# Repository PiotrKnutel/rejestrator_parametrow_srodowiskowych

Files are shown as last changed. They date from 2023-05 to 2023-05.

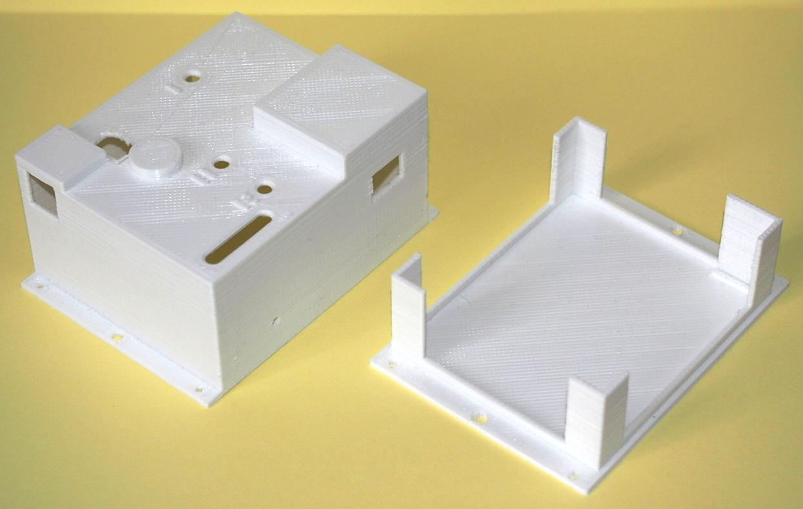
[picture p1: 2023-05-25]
zdjęcia/P2138913_v1.JPG

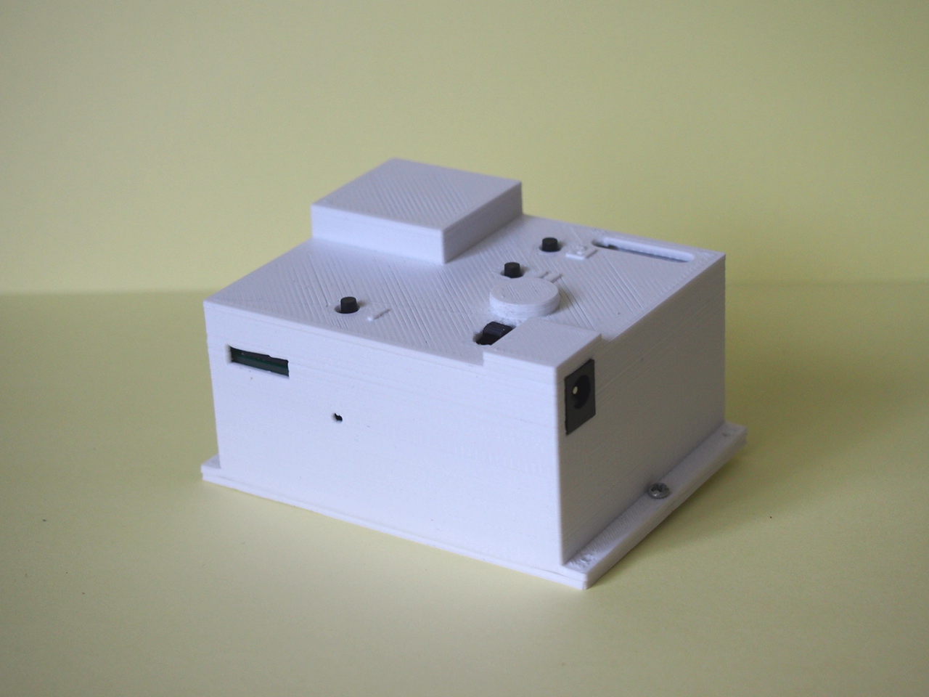
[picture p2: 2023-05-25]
zdjęcia/P2138927_v1.JPG

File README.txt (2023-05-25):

Projekt: Rejestaror Parametrów Środowiskowych
Project: The Recorder of Environmental Parameters
Autor/Author: Piotr Knutel (piknut@linux.pl), 2020-2021

Rejestrator dokonuje pomiarów: temperatury, ciśnienia
i wilgotności względnej powietrza atmosferycznego.

Projekt oparto o mikrokontroler z rodziny STM32
(STM32F103RC), cyfrowy czujnik BME280 i kartę micro-SD.

Pomiary wykonywane są cyklicznie (co ustalony czas,
np. 5, 10, 15, 30 min) lub na żądanie użytkownika
(przez naciśnięcie przycisku). Wyniki zapisywane są
w plikach CSV, na karcie SD. Ustawienia urządzenia
wprowadza się i odczytuje poprzez opracowaną aplikację
komputerową, która komunikuje się z rejestratorem,
przez wirtualny port szeregowy i przewód USB.  

Rejestrator może być stosowane do długookresowych
badań środowisk – takich jak miejsca funkcjonowania
ludzi i maszyn, magazyny oraz kontenery towarowe
– lub jako domowa stacja pogodowa. Urządzenie może
być zasilane przewodowo lub bateryjnie. 

Projekt obejmuje:
- schemat i projekt PCB (w programie KiCAD);
- program mikroprocesora STM32F103RC (w języku C,
  w oparciu o STMCube);
- terminalową aplikację komputerową do wprowadzania
  i odczytu ustawień poprzez port szeregowy (w języku
  C#, dla Windows i Linux);
– projekt obudowy (w programie FreeCAD).

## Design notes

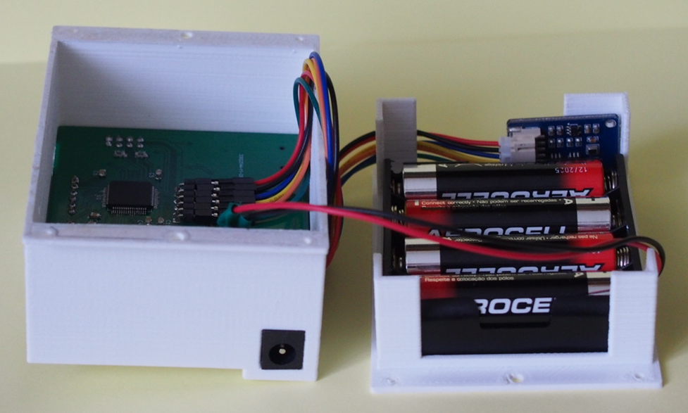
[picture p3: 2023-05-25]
zdjęcia/P2138917_v1.JPG

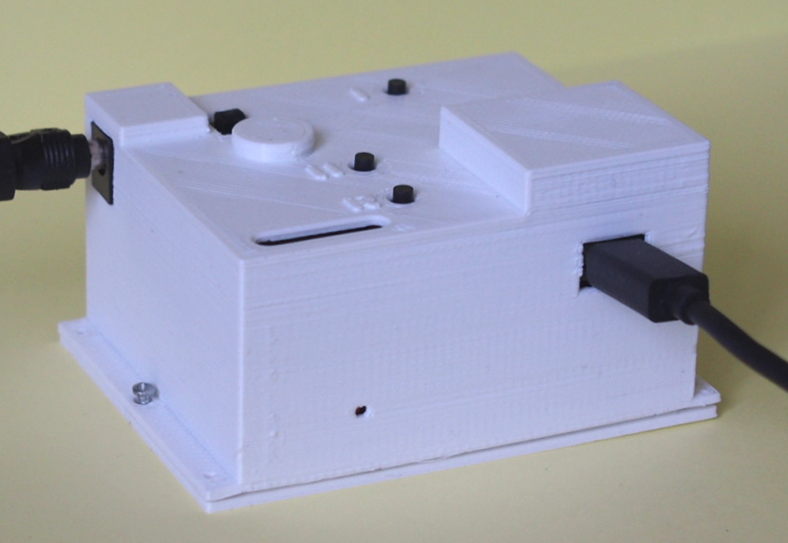
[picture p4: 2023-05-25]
zdjęcia/P2138921_v1.JPG

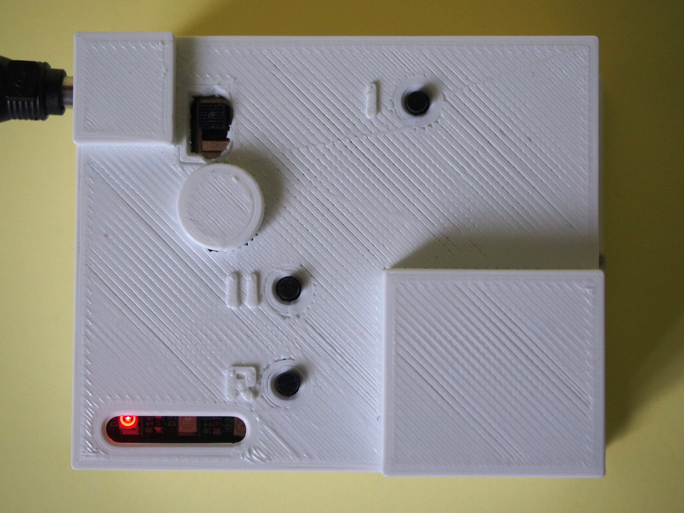
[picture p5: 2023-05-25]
zdjęcia/P2138924_v1.JPG

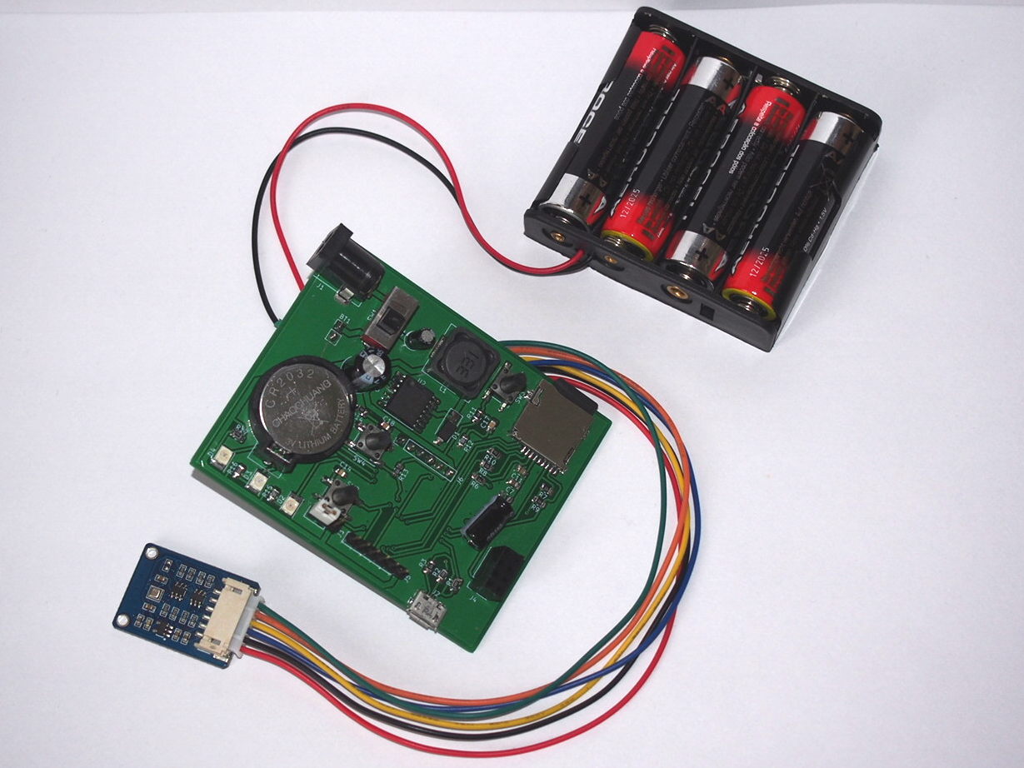
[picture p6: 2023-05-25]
zdjęcia/P2138910_v1.JPG

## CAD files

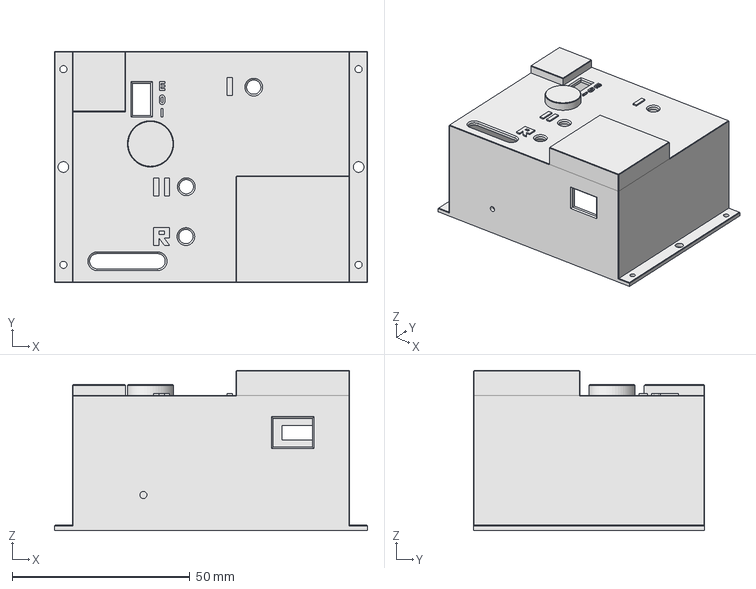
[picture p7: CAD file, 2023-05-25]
projekt_obudowy_FreeCAD/obudowa_rps.FCStd
88.0 x 65.0 x 45.0 mm

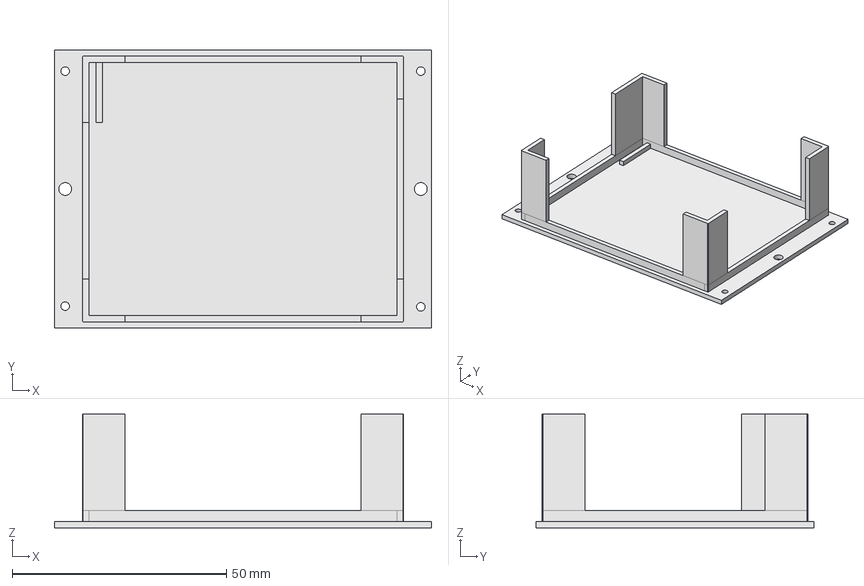
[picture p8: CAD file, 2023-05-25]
projekt_obudowy_FreeCAD/rps_obudowa_dol.FCStd
88.0 x 65.0 x 26.5 mm

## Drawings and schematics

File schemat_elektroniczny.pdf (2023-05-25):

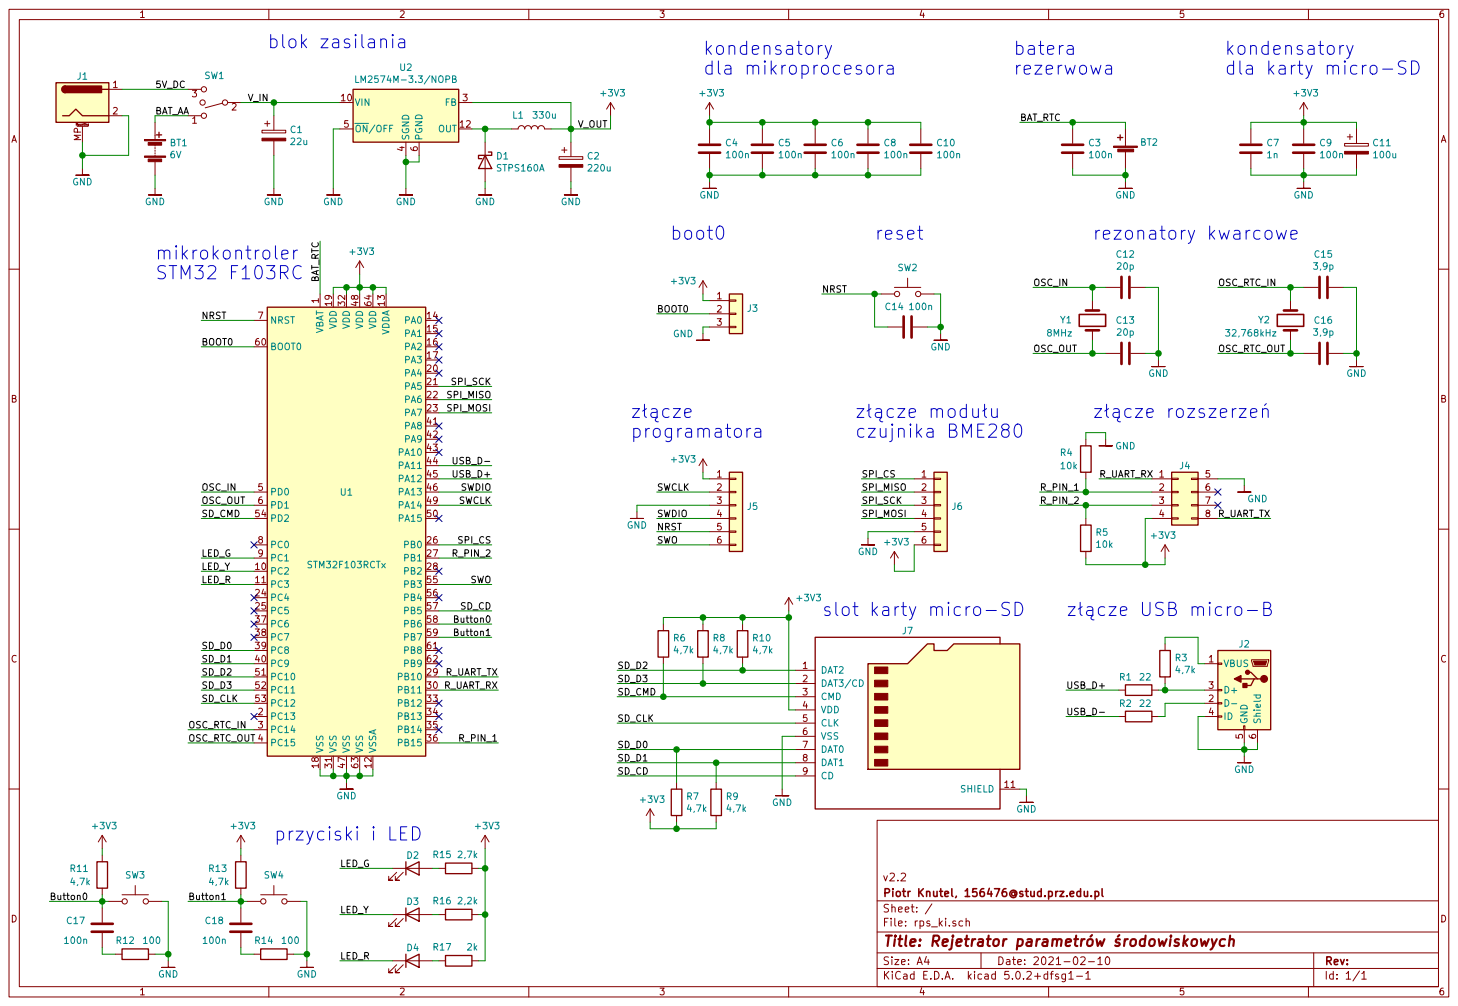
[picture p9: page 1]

kondensatory
dla karty micro-SD

1 PC2 10 PC3 11 VSSA 12 VDDA 13 PA0 14 PA1 15 PA2 16 PA3 17 VSS 18 VDD 19 PC13 2 PA4 20 PA5 21 PA6 22 PA7 23 PC4 24 PC5 25 PB0 26 PB1 27 PB2 28 PB10 29 PC14 3 PB11 30 VSS 31 VDD 32 PB12 33 PB13 34 PB14 35 PB15 36 PC6 37 PC7 38 PC8 39 PC15 4 PC9 40 PA8 41 PA9 42 PA10 43 PA11 44 PA12 45 PA13 46 VSS 47 VDD 48 PA14 49 PD0 5 PA15 50 PC10 51 PC11 52 PC12 53 PD2 54 PB3 55 PB4 56 PB5 57 PB6 58 PB7 59 PD1 6 BOOT0 60 PB8 61 PB9 62 VSS 63 VDD 64 NRST 7 PC0 8 PC1 9 U1 STM32F103RCTx BT2

File: rps_ki.sch Sheet: / Piotr Knutel, 156476@stud.prz.edu.pl v2.2 VBAT

slot karty micro-SD

Id: 1/1 Title: Rejetrator parametrów rodowiskowych

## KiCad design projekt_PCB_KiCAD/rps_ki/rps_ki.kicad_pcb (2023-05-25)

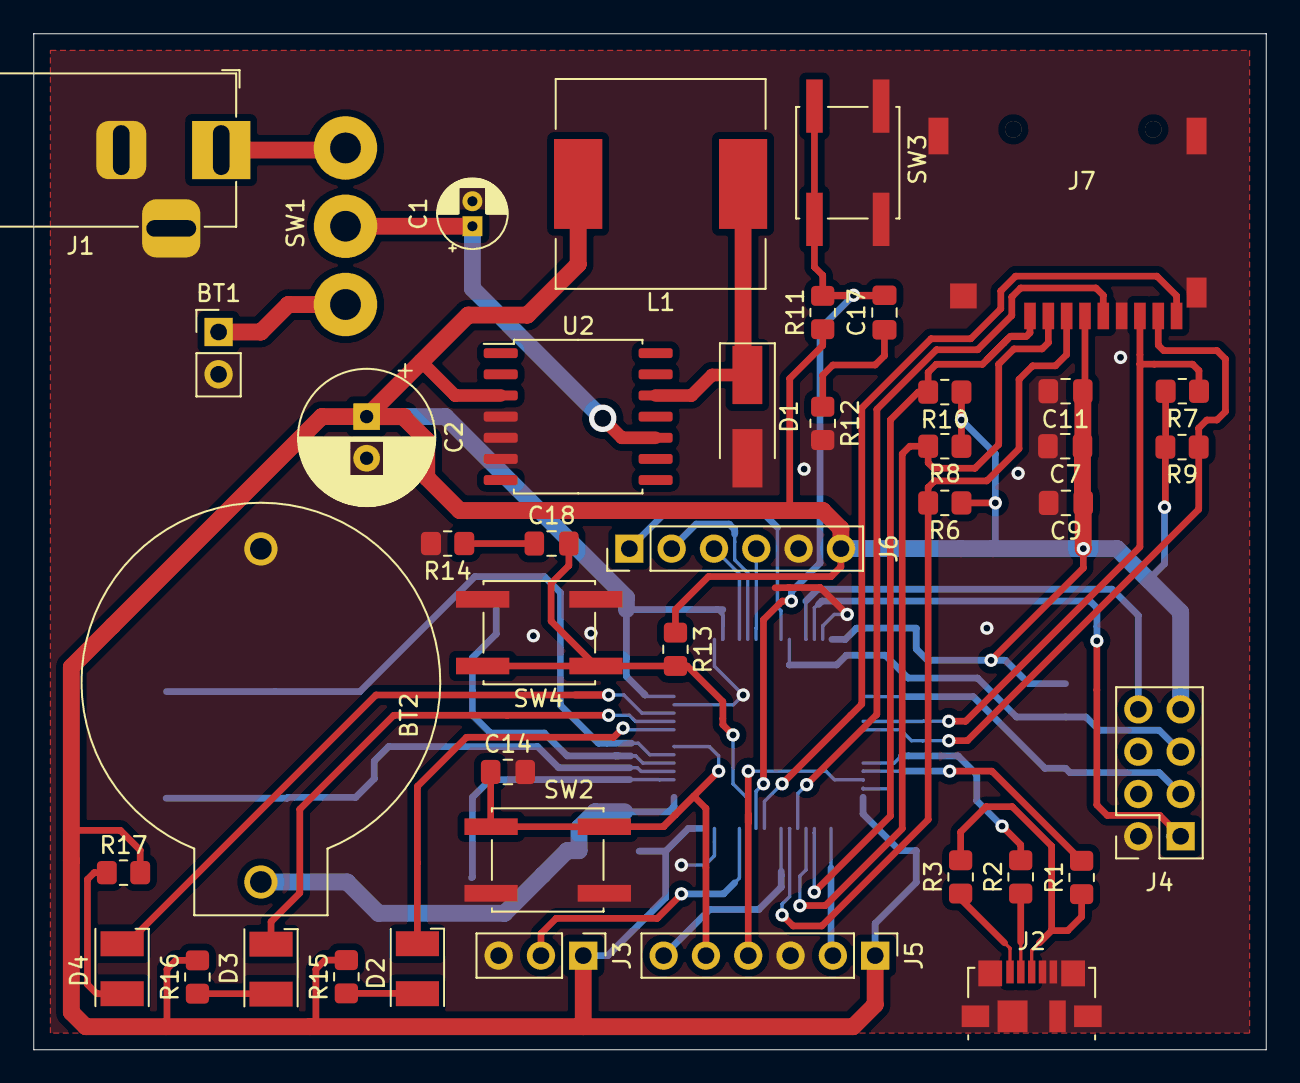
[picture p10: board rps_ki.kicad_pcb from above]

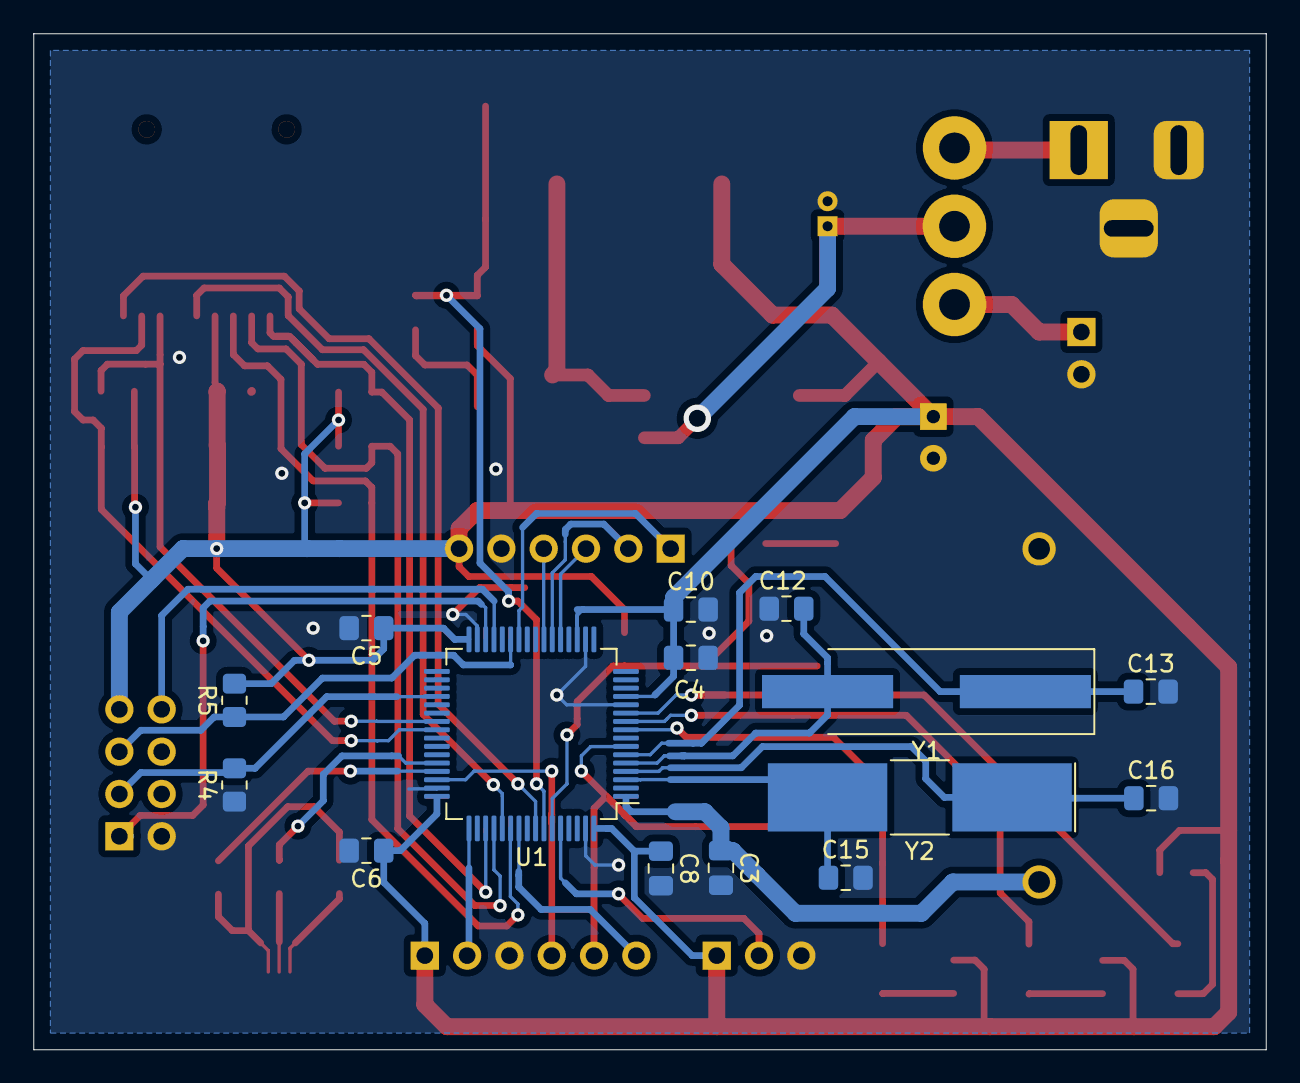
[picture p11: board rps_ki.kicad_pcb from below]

Board: 2 copper layers, 74.0 x 61.0 mm, 57 parts (15 on the bottom side), 46 nets.

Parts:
BT1: 6V; PinHeader_1x02_P2.54mm_Vertical
BT2: Battery_Cell; battery_holders_2032_horizontal_pk
C1: 22u; CP_Radial_D4.0mm_P1.50mm
C2: 220u; CP_Radial_D8.0mm_P2.50mm
C3, C7: 1n; C_0805_2012Metric_Pad1.18x1.45mm_HandSolder
C4, C5, C6, C8, C9, C10, C14, C17, C18: 100n; C_0805_2012Metric_Pad1.18x1.45mm_HandSolder
C11: 100u; C_0805_2012Metric_Pad1.18x1.45mm_HandSolder
C12, C13: 20p; C_0805_2012Metric_Pad1.18x1.45mm_HandSolder
C15, C16: 4,3p; C_0805_2012Metric_Pad1.18x1.45mm_HandSolder
D1: 11DQ06; D_SMA_Handsoldering
D2, D3, D4: LED; LED_PLCC-2
J1: Barrel_Jack_MountingPin; BarrelJack_Horizontal
J2: USB_B_Micro; USB_Micro-B_Molex_47346-0001
J3: Conn_01x03; PinHeader_1x03_P2.54mm_Vertical
J4: Conn_02x04_Top_Bottom; PinSocket_2x04_P2.54mm_Vertical_ESP8266-01_pk
J5, J6: Conn_01x06; PinHeader_1x06_P2.54mm_Vertical
J7: Micro_SD_Card_Det_zmodyfikowany; microSD_MCSP-Q-08-A-SG-DTE_pk
L1: 330u; L_12x12mm_H6mm
R1, R2: 20; R_0805_2012Metric_Pad1.20x1.40mm_HandSolder
R3, R11, R13: 4,7k; R_0805_2012Metric_Pad1.20x1.40mm_HandSolder
R4, R5: 10k; R_0805_2012Metric_Pad1.20x1.40mm_HandSolder
R6, R7, R8, R9, R10: 47k; R_0805_2012Metric_Pad1.20x1.40mm_HandSolder
R12, R14: 100; R_0805_2012Metric_Pad1.20x1.40mm_HandSolder
R15, R16, R17: 200; R_0805_2012Metric_Pad1.20x1.40mm_HandSolder
SW1: SW_SPDT_MSM; switch_5MS3S102AM2QE_pk
SW2, SW3, SW4: SW_Push; SW_SPST_EVQQ2
U1: STM32F103RCTx; LQFP-64_10x10mm_P0.5mm
U2: LM2574M-3.3; SOIC-14W_7.5x9mm_P1.27mm
Y1: 8MHz; Crystal_SMD_HC49-SD_HandSoldering
Y2: 32,768kHz; Crystal_SMD_SeikoEpson_MC405-2Pin_9.6x4.1mm_HandSoldering

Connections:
+3V3: C2.1, C4.1, C5.1, C6.1, C7.1, C8.1, C9.1, C10.1, C11.1, J3.1, J4.4, J5.1, J6.6, J7.4, L1.2, R5.2, R6.1, R7.2, R8.1, R9.2, R10.1, R11.1, R13.1, R15.2, R16.2, R17.2, U1.13, U1.19, U1.32, U1.48, U1.64, U2.3
/5V_DC: J1.1, SW1.3
/BAT_AA: BT1.1, SW1.1
/BAT_RTC: BT2.1, C3.1, U1.1
/BOOT0: J3.2, U1.60
/Button0: C17.2, R11.2, SW3.1, U1.58
/Button1: C18.2, R13.2, SW4.1, U1.59
/ESP_CH_PD: J4.2, R4.2, U1.36
/ESP_NRST: J4.3, R5.1, U1.27
/ESP_RX: J4.8, U1.29
/ESP_TX: J4.1, U1.30
/LED0: D2.1, U1.9
/LED1: D3.1, U1.10
/LED2: D4.1, U1.11
/NRST: C14.1, J5.5, SW2.1, U1.7
/OSC_IN: C12.1, U1.5, Y1.2
/OSC_OUT: C13.1, U1.6, Y1.1
/OSC_RTC_IN: C15.1, U1.3, Y2.2
/OSC_RTC_OUT: C16.1, U1.4, Y2.1
/SD_CD: J7.9, U1.57
/SD_CLK: J7.5, U1.53
/SD_CMD: J7.3, R6.2, U1.54
/SD_D0: J7.7, R7.1, U1.39
/SD_D1: J7.8, R9.1, U1.40
/SD_D2: J7.1, R10.2, U1.51
/SD_D3: J7.2, R8.2, U1.52
/SPI_CS: J6.1, U1.26
/SPI_MISO: J6.2, U1.22
/SPI_MOSI: J6.4, U1.23
/SPI_SCK: J6.3, U1.21
/SWCLK: J5.2, U1.49
/SWDIO: J5.4, U1.46
/SWO: J5.6, U1.55
/USB_D+: R1.2, U1.45
/USB_D-: R2.2, U1.44
/V_IN: C1.1, SW1.2, U2.10
GND: BT1.2, BT2.2, C1.2, C2.2, C3.2, C4.2, C5.2, C6.2, C7.2, C8.2, C9.2, C10.2, C11.2, C12.2, C13.2, C14.2, C15.2, C16.2, D1.2, J1.2, J1.3, J2.4, J2.5, J2.6, J3.3, J4.5, J5.3, J6.5, J7.6, J7.11, R4.1, R12.2, R14.2, SW2.2, SW3.2, SW4.2, U1.12, U1.18, U1.31, U1.47, U1.63, U2.4, U2.5, U2.6
unnamed: C17.1, R12.1
unnamed: C18.1, R14.1
unnamed: D1.1, L1.1, U2.12
unnamed: D2.2, R15.1
unnamed: D3.2, R16.1
unnamed: D4.2, R17.1
unnamed: J2.1, R3.1
unnamed: J2.2, R2.1
unnamed: J2.3, R1.1, R3.2

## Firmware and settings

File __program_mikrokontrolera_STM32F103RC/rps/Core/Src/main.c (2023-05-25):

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
/* Includes ------------------------------------------------------------------*/
#include "main.h"
#include "fatfs.h"
#include "rtc.h"
#include "sdio.h"
#include "spi.h"
#include "usb_device.h"
#include "gpio.h"

/* USER CODE BEGIN Includes */
#include <string.h>
#include <stdio.h>
#include "rps.h"
#include "sensor_bme280.h"
/* USER CODE END Includes */

/* USER CODE BEGIN PV */
extern RTC_TimeTypeDef Time;
extern RTC_DateTypeDef Date;
extern RTC_DateTypeDef DateComapare;
RTC_TimeTypeDef LastMeasTime;
uint8_t measurementInterval;
_Bool receivedDataFlag;
_Bool measurementAndSaveFlag;
_Bool  communicationModeFlag;
float t,p,rh;
/* USER CODE END PV */

void SystemClock_Config(void);
/* USER CODE BEGIN PFP */
void setAlarm(void);
/* USER CODE END PFP */

/* USER CODE BEGIN 0 */

void setAlarm()
{
	  HAL_RTC_DeactivateAlarm(&hrtc, RTC_ALARM_A);
	  HAL_RTC_GetTime(&hrtc, &Time, RTC_FORMAT_BIN);
	  uint8_t minutesAfterLastMeas = Time.Minutes % measurementInterval;
	  uint8_t minutesToNextMeas = measurementInterval - minutesAfterLastMeas;
	  RTC_AlarmTypeDef alarm = {0};
	  alarm.AlarmTime.Seconds = 0;
	  alarm.AlarmTime.Hours = Time.Hours;
	  alarm.AlarmTime.Minutes = Time.Minutes + minutesToNextMeas;
	  if (alarm.AlarmTime.Minutes > 59) {
		  ++(alarm.AlarmTime.Hours);
		  alarm.AlarmTime.Minutes -= 60;
	  }
	  if (alarm.AlarmTime.Hours > 23) {
		  alarm.AlarmTime.Hours -= 24;
	  }
	  HAL_RTC_SetAlarm(&hrtc, &alarm, RTC_FORMAT_BIN);
}

/* USER CODE END 0 */

/**
  * @brief  The application entry point.
  * @retval int
  */
int main(void)
{
  /* USER CODE BEGIN 1 */
  receivedDataFlag = 0;
  measurementAndSaveFlag = 0;
  communicationModeFlag = 0;
  /* USER CODE END 1 */

  /* MCU Configuration--------------------------------------------------------*/

  /*Reset of all peripherals, Initializes the Flash interface and the Systick.*/
  HAL_Init();

  /* Configure the system clock */
  SystemClock_Config();

  /* Initialize all configured peripherals */
  MX_GPIO_Init();
  MX_RTC_Init();
  MX_USB_DEVICE_Init();
  MX_SDIO_SD_Init();
  MX_FATFS_Init();
  MX_SPI1_Init();
  /* USER CODE BEGIN 2 */

  measurementInterval = readMeasurementIntervalFromBackupRegister();
  if(measurementInterval == 0) {												//jeśli rejestr jest wyzerowany, np. na skutek zaniku Vbat
	  measurementInterval = DEFAULT_MEASUREMENT_INTERVAL;
	  writeMeasurementIntervalToBackupRegister(measurementInterval);
  }

  if (__HAL_PWR_GET_FLAG(PWR_FLAG_WU) == 1) {
	  __HAL_PWR_CLEAR_FLAG(PWR_FLAG_WU);

	  HAL_GPIO_WritePin(GPIOC, LED_R_Pin, LED_ON);
	  HAL_Delay(500);
	  HAL_GPIO_WritePin(GPIOC, LED_R_Pin, LED_OFF);

	  HAL_RTC_GetTime(&hrtc, &Time, RTC_FORMAT_BIN);
	  HAL_RTC_GetDate(&hrtc, &Date, RTC_FORMAT_BIN);
	  writeDateToBackupRegister();

	  readLastMeasTimeFromBKUP(&LastMeasTime);
	  if ((Time.Minutes != LastMeasTime.Minutes)
			  || (Time.Hours != LastMeasTime.Hours)) {
		  BME280measurement(&t, &p, &rh);
		  saveDataToSDCard(t, p, rh);
		  writeLastMeasTimeToBKUP(&Time);
	  }
	  setAlarm();
	  HAL_PWR_EnterSTANDBYMode();
  }

  /* Czas na naciśniecie przycisku II, w celu wejścia w tryb komunikacji.
     Czas na ewentualne rozpoczęcie wgrywania nowego programu. */
  HAL_GPIO_WritePin(GPIOC, LED_R_Pin, LED_ON);	//
  HAL_Delay(2000);								//
  HAL_GPIO_WritePin(GPIOC, LED_R_Pin, LED_OFF);	//
  /* USER CODE END 2 */

  /* Infinite loop */
  /* USER CODE BEGIN WHILE */
  do
  {
	  HAL_RTC_GetTime(&hrtc, &Time, RTC_FORMAT_BIN);
	  HAL_RTC_GetDate(&hrtc, &Date, RTC_FORMAT_BIN);
	  if (Date.Date != DateComapare.Date) {
		writeDateToBackupRegister();
	    DateComapare = Date;
	  }
	  readLastMeasTimeFromBKUP(&LastMeasTime);
	  if (((Time.Minutes % measurementInterval) == 0) && ((Time.Minutes
			  != LastMeasTime.Minutes) || (Time.Hours != LastMeasTime.Hours))) {
			  	  measurementAndSaveFlag = 1;
	  }
	  if (measurementAndSaveFlag) {
		 BME280measurement(&t, &p, &rh);
		 saveDataToSDCard(t, p, rh);
		 writeLastMeasTimeToBKUP(&Time);
		 measurementAndSaveFlag = 0;
	  }
	  if(communicationModeFlag && receivedDataFlag) {
	  	tasksWithReceivedDataFromPC();
	  	receivedDataFlag = 0;
	  }

  } while (measurementAndSaveFlag || communicationModeFlag);

  setAlarm();
  HAL_PWR_EnterSTANDBYMode();

    /* USER CODE END WHILE */

}

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
/* USER CODE BEGIN 4 */
void HAL_GPIO_EXTI_Callback(uint16_t button)
{
	if (button == BUTTON_A_Pin) {
		measurementAndSaveFlag = 1;
	}
	if (button == BUTTON_B_Pin) {
		if(!communicationModeFlag) {
			HAL_GPIO_WritePin(LED_Y_GPIO_Port, LED_Y_Pin, LED_ON);
			communicationModeFlag = 1;
		} else {
			HAL_GPIO_WritePin(LED_Y_GPIO_Port, LED_Y_Pin, LED_OFF);
			communicationModeFlag = 0;
		}
	}
}


/* USER CODE END 4 */
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


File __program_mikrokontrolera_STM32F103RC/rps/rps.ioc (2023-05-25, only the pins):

Mcu.UserName=STM32F103RCTx
PA11.Signal=USB_DM
PA12.Signal=USB_DP
PA13.Signal=SYS_JTMS-SWDIO
PA14.Signal=SYS_JTCK-SWCLK
PA5.Signal=SPI1_SCK
PA6.Signal=SPI1_MISO
PA7.Signal=SPI1_MOSI
PB0.GPIO_Label=BME280_CS
PB0.Signal=GPIO_Output
PB5.GPIO_Label=SD_CD
PB5.Signal=GPIO_Input
PB6.GPIO_Label=BUTTON_A
PB6.Signal=GPXTI6
PB7.GPIO_Label=BUTTON_B
PB7.Signal=GPXTI7
PC1.GPIO_Label=LED_G
PC1.Signal=GPIO_Output
PC12.Signal=SDIO_CK
PC14-OSC32_IN.Signal=RCC_OSC32_IN
PC15-OSC32_OUT.Signal=RCC_OSC32_OUT
PC2.GPIO_Label=LED_Y
PC2.Signal=GPIO_Output
PC3.GPIO_Label=LED_R
PC3.Signal=GPIO_Output
PC8.Signal=SDIO_D0
PD0-OSC_IN.Signal=RCC_OSC_IN
PD1-OSC_OUT.Signal=RCC_OSC_OUT
PD2.Signal=SDIO_CMD

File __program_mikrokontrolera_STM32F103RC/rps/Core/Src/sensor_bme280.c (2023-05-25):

/* Rejestrator parametrów środowiskowych; Piotr Knutel; v1.0; sensor_bme280.c */

#include "sensor_bme280.h"

extern float lastTemperature, lastPressure, lastHumidity;
extern uint8_t lastMeasurementInfoString[300];

uint8_t BME280id;
uint8_t BME280config;
uint8_t status;
uint8_t conf1, meas1, ctrl_hum1;
int32_t tFine;
unsigned short digT1, digP1;
short digT2, digT3, digP2, digP3, digP4, digP5, digP6, digP7, digP8, digP9,
	  digH2, digH4, digH5;
unsigned char digH1, digH3;
char digH6;
uint8_t dig1[26];
uint8_t dig2[7];

void clearTable(uint8_t *tab)
{
	for (int i = 0; i < sizeof(tab); ++i) {
		tab[i] = 0;
	}
}

void BME280Read(uint8_t address, uint8_t numberOfBytes, uint8_t* answer)
{
	uint8_t *tx, *rx;
	tx = malloc((numberOfBytes + 1) * sizeof *tx);
	rx = malloc((numberOfBytes + 1) * sizeof *rx);
	tx[0] = address | (1<<7); //dla odczytu pamięci, 7 bit adresu jest zawsze 1
	clearTable(answer);
	HAL_GPIO_WritePin(BME280_CS_GPIO_Port, BME280_CS_Pin, RESET);
	HAL_SPI_TransmitReceive(SPI_BME280, tx, rx, numberOfBytes + 1, 5);
	HAL_GPIO_WritePin(BME280_CS_GPIO_Port, BME280_CS_Pin, SET);
	for (int i = 0; i < numberOfBytes; ++i) {
		answer[i] = rx[i + 1];
	}
	free(rx);
	free(tx);
}

uint8_t BME280Write(uint8_t address, uint8_t data)
{
	uint8_t tx[2];
	uint8_t verify = 0;
	uint8_t oldData = 0;
	uint8_t mask = 0;
	if ((address != BME280_ADDRESS_CONFIG)
			&& (address != BME280_ADDRESS_CTRL_MEAS)
			&& (address != BME280_ADDRESS_CTRL_HUM)
			&& (address != BME280_ADDRESS_RESET))
		return STATUS_WRONG_ARGUMENT;
	switch (address) {
		case BME280_ADDRESS_CONFIG:
			mask = 0b00000010;
			break;
		case BME280_ADDRESS_CTRL_HUM:
			mask = 0b11111000;
			break;
	}
	BME280Read(address, 1, &oldData);
	data &= ~mask;																//wyzeruje bity argumentu data, które nie powinno się zmieniać (dokumentacja BME280 str. 27)
	data |= (oldData & mask);													//wyzeruje stare bity, które można zmieniać i w ich miejsce wstawi nowe
	tx[0] = address & 0b01111111;												//dla zapisu do pamięci 7 bit adresu jest zawsze 0
	tx[1] = data;
	HAL_GPIO_WritePin(BME280_CS_GPIO_Port, BME280_CS_Pin, RESET);
 	HAL_SPI_Transmit(SPI_BME280, tx, 2, 5);
	HAL_GPIO_WritePin(BME280_CS_GPIO_Port, BME280_CS_Pin, SET);
	if (address == BME280_ADDRESS_RESET) {
		return STATUS_OK;
	}
 	BME280Read(address, 1, &verify);
 	if (verify == data)
 		return STATUS_OK;
 	else
 		return STATUS_ERROR;
}
int32_t BME280compensateT(int32_t adcT)
{  //dokumentacja BME280 str. 25)
	int32_t var1, var2, T;
	var1 = ((((adcT >> 3) - ((int32_t)digT1 << 1))) * ((int32_t)digT2)) >> 11;
	var2 = (((((adcT >> 4) - ((int32_t)digT1)) * ((adcT >> 4)
			- ((int32_t)digT1))) >> 12) * ((int32_t)digT3)) >> 14;
	tFine = var1 + var2;
	T = (tFine * 5 + 128) >> 8;
	return T;
}

uint32_t BME280compensateP(int32_t adcP)
{
	int64_t var1, var2, p;
	var1 = ((int64_t)tFine) - 128000;
	var2 = var1 * var1 * (int64_t)digP6;
	var2 = var2 + ((var1 * (int64_t)digP5) << 17);
	var2 = var2 +(((int64_t)digP4) << 35);
	var1 = ((var1*var1* (int64_t)digP3) >> 8) + ((var1 * (int64_t)digP2) << 12);
	var1 = (((((int64_t)1) << 47) + var1)) * ((int64_t)digP1) >> 33;
	if (var1 == 0) {
		return 0;
	}
	p = 1048576 - adcP;
	p = (((p << 31) - var2) * 3125) / var1;
	var1 = (((int64_t)digP9) * (p >> 13) * (p >> 13)) >> 25;
	var2 = (((int64_t)digP8) * p) >> 19;
	p = ((p + var1 + var2) >> 8) + (((int64_t)digP7) << 4);
	return (uint32_t)p;
}

uint32_t BME280compensateH(int32_t adcH)
{
	int32_t v;
	v = (tFine - ((int32_t)76800));
	v = (((((adcH <<14) - (((int32_t)digH4) << 20) - (((int32_t)digH5) * v))
			+ ((int32_t)16384)) >> 15) * (((((((v * ((int32_t)digH6)) >> 10)
					* (((v*((int32_t)digH3)) >> 11) + ((int32_t)32768))) >> 10)
					+ ((int32_t)2097152)) * ((int32_t)digH2) + 8192) >> 14));
	v = (v - (((((v >> 15) * (v >> 15)) >> 7) * ((int32_t)digH1)) >> 4));
	v = (v < 0 ? 0 : v);
	v = (v > 419430400 ? 419430400 : v);
	return (uint32_t)(v >> 12);
}

void BME280measurement(float* outTemperature, float* outPressure,
		float* outHumidity)
{

	/* Obsługa BME280 */
	  uint8_t temp[3] = {0, 0, 0};
	  uint8_t press[3] = {0, 0, 0};
	  uint8_t hum[2] = {0, 0};
	  uint8_t allADC[8] = {0, 0, 0, 0, 0, 0, 0, 0};
	  uint8_t t_sb, filter, spi3w_en, config, osrs_p, osrs_t, mode, ctrl_meas,
	  	  	  ctrl_hum;

	  t_sb = BME280_T_SB_20MS;
	  filter = BME280_FILTER_OFF;
	  spi3w_en = BME280_SPI3W_EN_OFF;
	  config = 0 | (t_sb << 5) | (filter << 2) | spi3w_en;
	  osrs_t = BME280_OSRS_X1;
	  osrs_p = BME280_OSRS_X1;
	  mode = BME280_MODE_FORCED;
	  ctrl_meas = (osrs_t << 5) | (osrs_p << 2) | mode;
	  ctrl_hum = BME280_OSRS_X1;

	  BME280Write(BME280_ADDRESS_RESET, BME280_RESET);
	  HAL_Delay(10);
	  BME280Read(BME280_ADDRESS_ID, 1, &BME280id);
	  status = BME280Write(BME280_ADDRESS_CONFIG, config);
	  status = BME280Write(BME280_ADDRESS_CTRL_MEAS, ctrl_meas);
	  status = BME280Write(BME280_ADDRESS_CTRL_HUM, ctrl_hum);
	  status = BME280Write(BME280_ADDRESS_CTRL_MEAS, ctrl_meas);

	  HAL_Delay(12);
	  BME280Read(BME280_ADDRESS_CONFIG, 1, &conf1);
	  BME280Read(BME280_ADDRESS_CTRL_MEAS, 1, &meas1);
	  BME280Read(BME280_ADDRESS_CTRL_HUM, 1, &ctrl_hum1);
	  BME280Read(BME280_ADDRESS_FIRST_BYTE_OF_ADC_VALUE, 8, allADC);
	  BME280Read(0x88, 26, dig1);
	  BME280Read(0xE1, 7, dig2);
	  digT1 = (unsigned short)((dig1[1] << 8) | dig1[0]);
	  digT2 = (short)((dig1[3] << 8) | dig1[2]);
	  digT3 = (short)((dig1[5] << 8) | dig1[4]);
	  digP1 = (unsigned short)((dig1[7] << 8) | dig1[6]);
	  digP2 = (short)((dig1[9] << 8) | dig1[8]);
	  digP3 = (short)((dig1[11] << 8) | dig1[10]);
	  digP4 = (short)((dig1[13] << 8) | dig1[12]);
	  digP5 = (short)((dig1[15] << 8) | dig1[14]);
	  digP6 = (short)((dig1[17] << 8) | dig1[16]);
	  digP7 = (short)((dig1[19] << 8) | dig1[18]);
	  digP8 = (short)((dig1[21] << 8) | dig1[20]);
	  digP2 = (short)((dig1[23] << 8) | dig1[22]);
	  digH1 = (unsigned char)dig1[25];
	  digH2 = (short)((dig2[1] << 8) | dig2[0]);
	  digH3 = (unsigned char)dig2[2];
	  digH4 = (short)((dig2[3] << 4) | (dig2[4] & 0x0F));
	  digH5 = (short)(((dig2[4] & 0xF0) >> 4) | (dig2[5] << 4));
	  digH6 = (char)dig2[6];
	  press[0] = allADC[0];
	  press[1] = allADC[1];
	  press[2] = allADC[2];
	  temp[0] = allADC[3];
	  temp[1] = allADC[4];
	  temp[2] = allADC[5];
	  hum[0] = allADC[6];
	  hum[1] = allADC[7];
	  int32_t t, p, h;
	  t = p = h = 0;
	  t = (int32_t)((temp[0] << 12) | (temp[1] << 4) | (temp[2] >> 4));
	  p = (int32_t)((press[0] << 12) | (press[1] << 4) | ((press)[2] >> 4));
	  h = (int32_t)((hum[0] << 8) | hum[1]);
	  int ti = BME280compensateT(t);
	  uint32_t pi = BME280compensateP(p);
	  uint32_t hi = BME280compensateH(h);
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

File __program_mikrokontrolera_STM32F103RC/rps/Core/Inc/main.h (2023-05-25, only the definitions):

#define LED_ON							RESET
#define LED_OFF 						SET
#define DEFAULT_MEASUREMENT_INTERVAL	10;
#define LED_G_Pin GPIO_PIN_1
#define LED_G_GPIO_Port GPIOC
#define LED_Y_Pin GPIO_PIN_2
#define LED_Y_GPIO_Port GPIOC
#define LED_R_Pin GPIO_PIN_3
#define LED_R_GPIO_Port GPIOC
#define BME280_CS_Pin GPIO_PIN_0
#define BME280_CS_GPIO_Port GPIOB
#define SD_CD_Pin GPIO_PIN_5
#define SD_CD_GPIO_Port GPIOB
#define BUTTON_A_Pin GPIO_PIN_6
#define BUTTON_A_GPIO_Port GPIOB
#define BUTTON_A_EXTI_IRQn EXTI9_5_IRQn
#define BUTTON_B_Pin GPIO_PIN_7
#define BUTTON_B_GPIO_Port GPIOB
#define BUTTON_B_EXTI_IRQn EXTI9_5_IRQn

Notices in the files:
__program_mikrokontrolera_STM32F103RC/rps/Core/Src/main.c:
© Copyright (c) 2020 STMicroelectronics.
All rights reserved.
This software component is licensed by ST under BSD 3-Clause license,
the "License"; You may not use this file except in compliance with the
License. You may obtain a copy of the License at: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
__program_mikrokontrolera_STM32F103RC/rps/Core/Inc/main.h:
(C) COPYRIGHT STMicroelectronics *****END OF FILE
